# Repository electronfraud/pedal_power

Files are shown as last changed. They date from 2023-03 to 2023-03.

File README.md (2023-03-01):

# Pedal Power

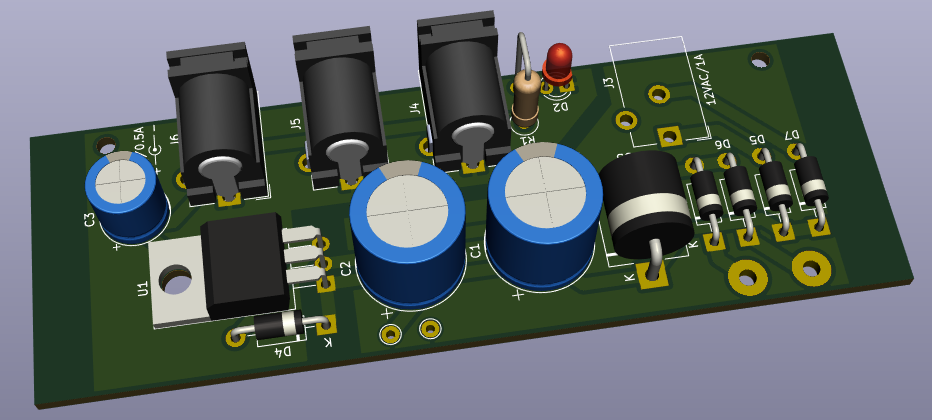
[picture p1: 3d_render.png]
3D rendering of a printed circuit board


This is a power supply for guitar pedals. It's a basic AC-DC converter that I built to get
comfortable with rectifying mains AC. Unlike most AC adapters, it's a linear power supply, not
switching. The reason I built it this way is because I wanted low noise since this is for an
audio application. It's also much simpler than a switching supply. The tradeoff is that it's
bigger, less efficient, and hotter, but that's an acceptable trade for a pedalboard. I used
exclusively through-hole parts to make it easier to build (and to repair when it eventually
breaks).

**N.B.:** For reasons lost to the sands of time, guitar pedal power jacks are wired **center
negative**. This is not how the vast majority of other DC receptacles are wired. Keep that in
mind if you decide to make this and want to plug it into something normal.

## Specifications

- Input: 115/120V, 50/60Hz AC
- Output: 9V DC, center negative, up to 500mA total across three jacks
- Reassuring power light

There's room on the board for a 12V/1A AC output&mdash;I had an ancient tube compressor that needed
this&mdash;but I didn't end up populating that in the actual build.

## Enclosure

I enclosed the PCB and transformer in a [Hammond 1455KHD1201BK](https://www.hammfg.com/electronics/small-case/extruded/1455nhd).
The case is attached to the ground terminal on the power entry module (see "Other Parts" below).

For heat dissipation, the regulator (U1) is attached to the enclosure with a strip of aluminum I
cut from a soda can and some thermally conductive double-sided tape.

## Other Parts

A couple parts aren't specified in the schematic:

- Transformer: Hammond 166GD12
- Power entry module: Schaffner FN285-2-06

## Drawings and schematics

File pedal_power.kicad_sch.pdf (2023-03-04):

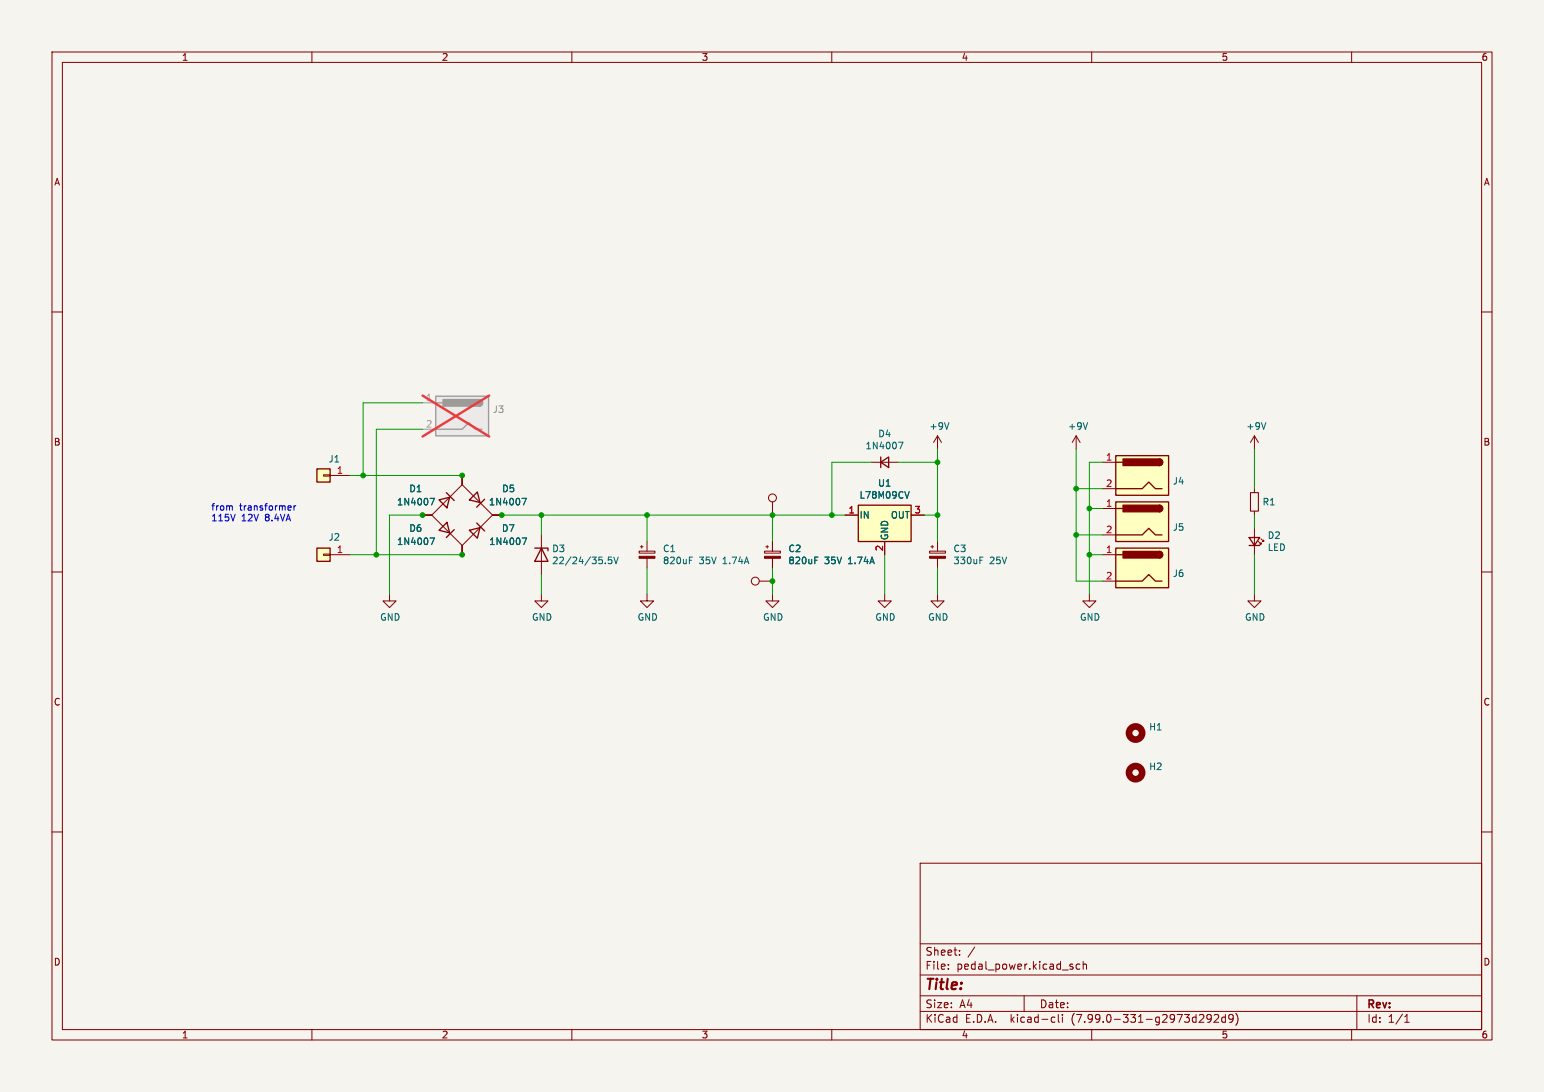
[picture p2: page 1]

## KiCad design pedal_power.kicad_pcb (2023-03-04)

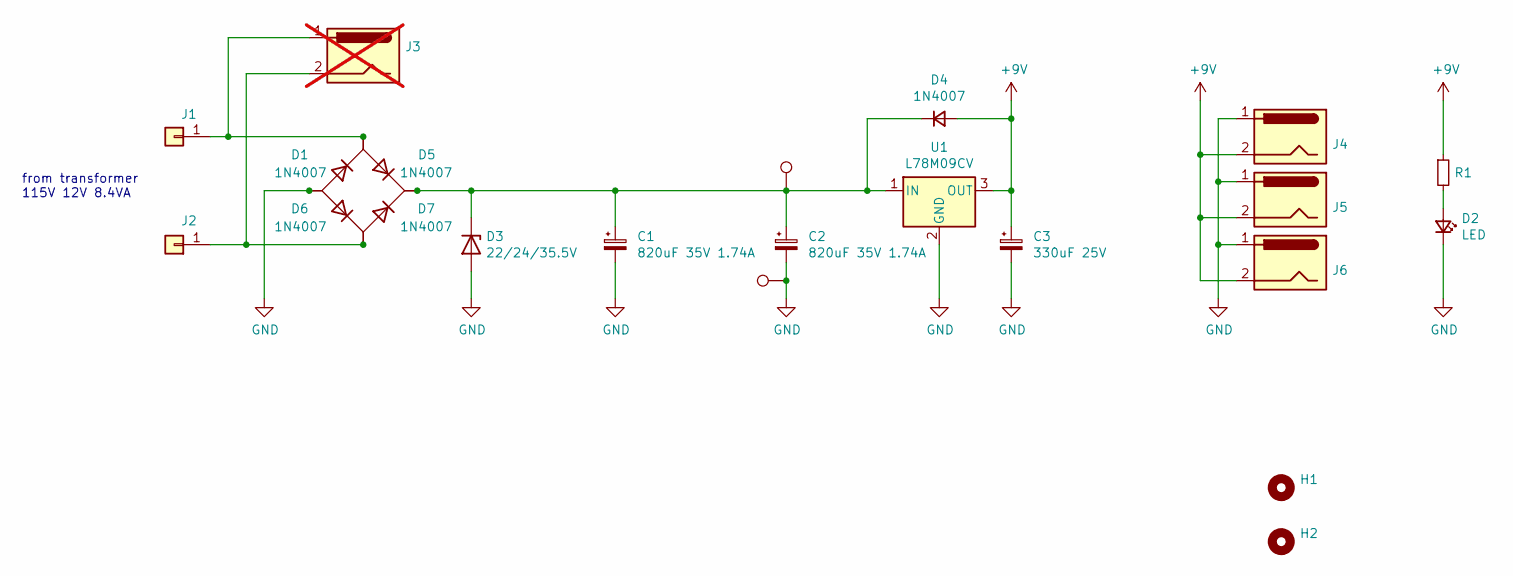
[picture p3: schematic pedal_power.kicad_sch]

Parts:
C1, C2: 820uF 35V 1.74A; CP_Radial_D12.5mm_P5.00mm
C3: 330uF 25V; CP_Radial_D8.0mm_P3.50mm
D1, D4, D5, D6, D7: 1N4007; D_DO-41_SOD81_P10.16mm_Horizontal
D2: LED; LED_D3.0mm
D3: 22/24/35.5V; D_P600_R-6_P12.70mm_Horizontal
H1, H2: MountingHole; MountingHole_2.2mm_M2
J1: L; SolderWirePad_1x01_Drill2mm
J2: N; SolderWirePad_1x01_Drill2mm
J3: Barrel_Jack; BarrelJack_CUI_PJ-102AH_Horizontal; not fitted
J4, J5, J6: Barrel_Jack; BarrelJack_CUI_PJ-102AH_Horizontal
R1: R_Small; R_Axial_DIN0309_L9.0mm_D3.2mm_P5.08mm_Vertical
TP1, TP2: TestPoint; TestPoint_THTPad_D2.0mm_Drill1.0mm
U1: L78M09CV; TO-220-3_Horizontal_TabDown

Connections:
+9V: C3.1, D4.2 (A), J4.2, J5.2, J6.2, R1.1, U1.3 (OUT)
GND: C1.2, C2.2, C3.2, D1.2 (A), D2.1 (K), D3.2 (A), D6.2 (A), J4.1, J5.1, J6.1, TP2.1, U1.2 (GND)
unnamed: C1.1, C2.1, D3.1 (K), D4.1 (K), D5.1 (K), D7.1 (K), TP1.1, U1.1 (IN)
unnamed: D1.1 (K), D5.2 (A), J1.1, J3.1
unnamed: D2.2 (A), R1.2
unnamed: D6.1 (K), D7.2 (A), J2.1, J3.2

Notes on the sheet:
from transformer 115V 12V 8.4VA

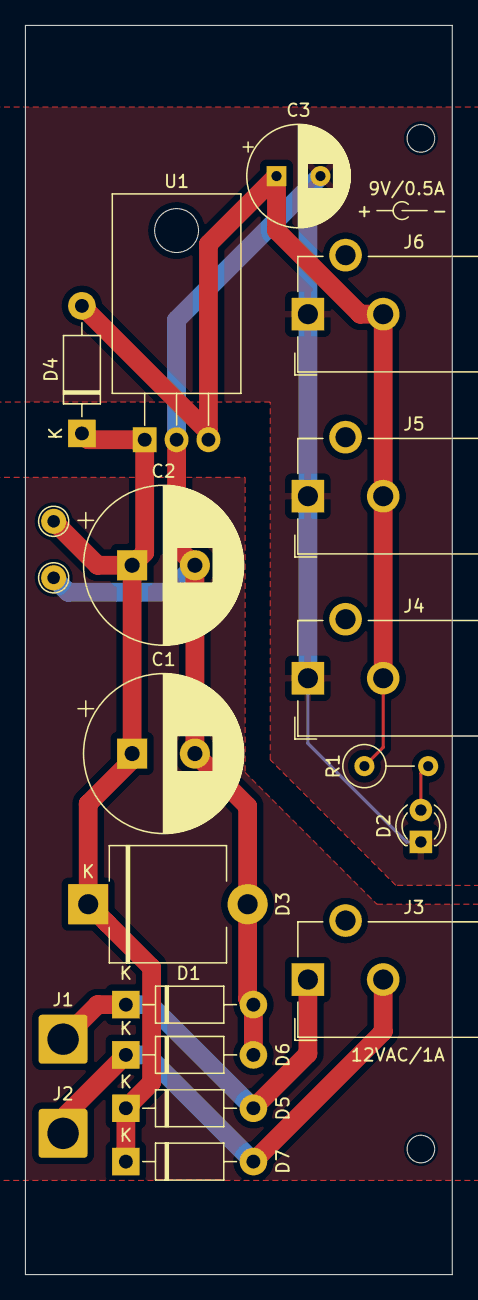
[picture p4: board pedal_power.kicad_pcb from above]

Board: 2 copper layers, 34.0 x 99.5 mm, 22 parts (0 on the bottom side), 6 nets.

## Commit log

2023-03-01 fix PJ-102AH 3d model
    [pedal_power.kicad_pcb]
2023-03-02 tidy up schematic
    [pedal_power.kicad_pcb, pedal_power.sch]
2023-03-04 update to kicad 7 and add plot workflow
    [pedal_power.kicad_pcb, pedal_power.kicad_sch, pedal_power.sch]
2023-03-04 plot schematics
